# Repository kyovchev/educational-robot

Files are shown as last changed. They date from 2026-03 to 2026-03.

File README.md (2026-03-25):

# MECHO: Modular Extensible Cobot for Human-Centered Operations

This repository contains files for the development of modular robotic arm platform.

The platform is based on the well-known Feetech STS3215-12V smart servo motors: [https://www.dfrobot.com/product-2962.html](https://www.dfrobot.com/product-2962.html).

It was also tested with Herkulex DRS-0101, but they have requirement for 7.5V power supply and encoder with a lower resolution. Also, the Dynamixel AX-12A was considered, but the dimensions were not suitable for the application.

Different constructions can be built by using the following parts:

1. Actuator motor housing;
2. Actuator output ring;
3. 90-degree bracket cover;
4. 15 mm spacer;
5. 90-degree bracket;
6. Base clamp mount bracket;
7. Base box;
8. Base cover;
9. Gripper mounting bracket;
10. Tool mounting bracket.

The parts are shown in the following image:

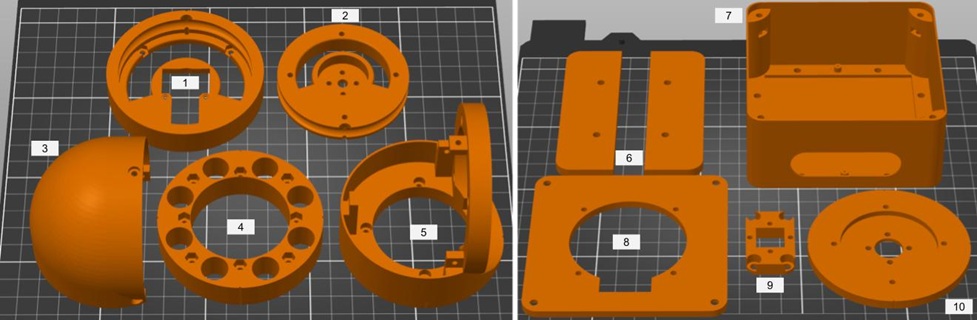
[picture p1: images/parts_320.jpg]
Parts


For the robotic gripper the Micro Servo Parallel Gripper by Techniccontroller is used: [https://grabcad.com/library/micro-servo-parallel-gripper-1](https://grabcad.com/library/micro-servo-parallel-gripper-1).

Currently, the control box of the robot. For the control of the robot an [Arduino Mega 2560 board](https://store.arduino.cc/products/arduino-mega-2560-rev3) is used. for the communication with the servo motors a dedicated [Serial Bus Servo Driver Board](https://www.dfrobot.com/product-3002.html) is connected to a UART port of the Arduino. An additional [25W DC-DC Power Module](https://www.dfrobot.com/product-752.html) is added to the control box for providing stable 5V output for the end effector and if needed also for the Arduino.

The robot assembled in a 6 degree of freedom configuration and the control box are shown in the following image.

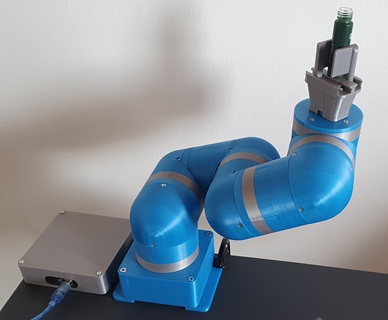
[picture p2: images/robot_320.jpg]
Robot and control box


## Experiments and Videos

Executions of the Task Board v2023 tasks: button press and circuit probing tasks of the Task Board v2023: [https://github.com/peterso/robotlearningblock](https://github.com/peterso/robotlearningblock) are shown in the following video: [https://youtu.be/xAtnlniCpGE](https://youtu.be/Kb3CY3zpSdE).

Demonstration of the execution of a task to pick up a bottle lying in a horizontal position and place it in another place, but this time in a vertical position is shown in the following video: [https://youtu.be/xAtnlniCpGE](https://youtu.be/xAtnlniCpGE).

The Pack Bottle Task Executed by the Education Cobot (https://youtu.be/xAtnlniCpGE)

## CAD and STL files

In the folder [CAD](./CAD/) you can find the source CAD files. They were delevoped by using the FreeCAD software: [https://www.freecad.org/](https://www.freecad.org/).

Differenr robot configurations with 4, 5 or 6 degrees of freedom in a CAD environment can be found in the folder [CAD/Assemblies](./CAD/Assemblies/).

In the folder [STLs](./STLs/) you can find the exported STL files which can be 3D printed.

## Kinematics

In the folder [Kinematics](./Kinematics/) you will find a useful example Jupyter notebooks which shows how the forward and inverse kinematics can be solved by using Robotics Toolbox for Python.

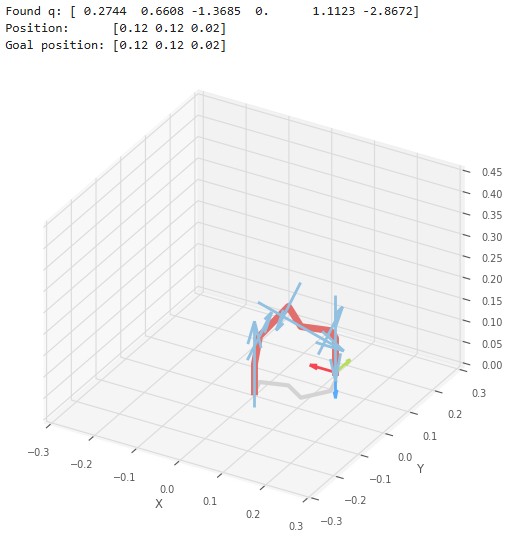
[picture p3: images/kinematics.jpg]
Inverse kinematics


## Software

The folder [Software](./Software/) contains useful Python packages and application for the control of the robot when STS3215 servo motors are used. 

You can run the control software with the following commands:

```bash
cd Software
python app.py
```

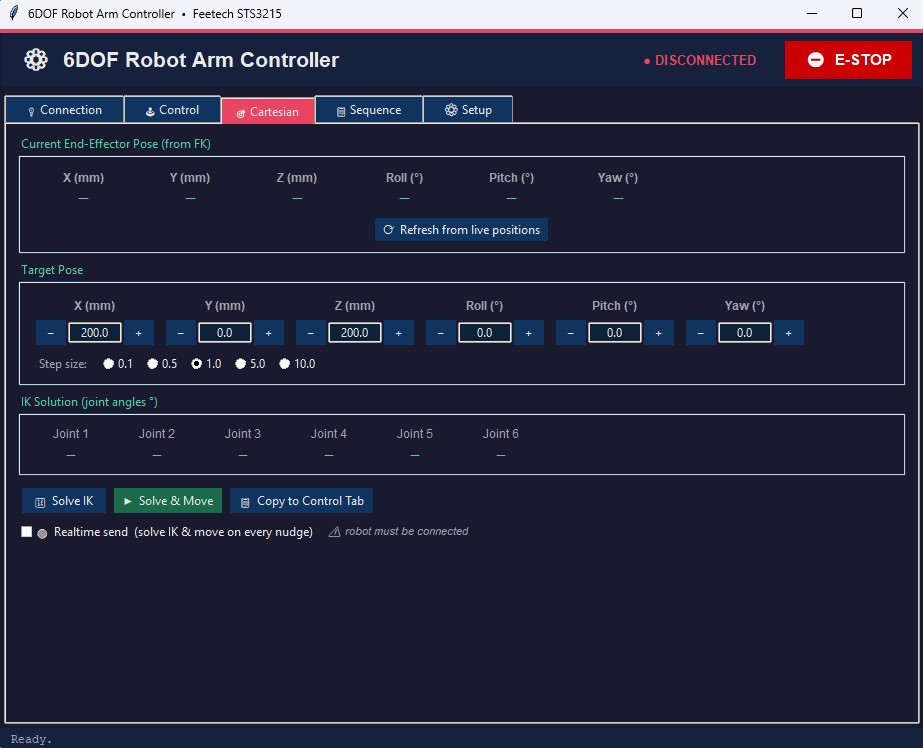
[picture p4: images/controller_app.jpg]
Robot Arm Controller App


It is still under active development.

There are also `robot_api` and `robot_arm` python packages which can be installed locally and used for coding python programs for the control of the robot. The packages can be installed locally in editable mode with: `pip install -e .`. An example program can be found in [./Software/test_api.py](./Software/test_api.py). This API is similar to the Python API for the commercial xArm cobots: [https://github.com/xArm-Developer/xArm-Python-SDK](https://github.com/xArm-Developer/xArm-Python-SDK).

You can also find the firmware for the Arduino board in the folder [./Software/arduino_controller/](./Software/arduino_controller/). This firware allows you to use a regular PWM (micro) servo for the gripper. The firmware will assign to it a virtual ID 7 and be able to control it with the same library and commands as those for the other smart STS3215-12V servos. The library for the servos is described in [https://github.com/vassar-robotics/feetech-servo-sdk](https://github.com/vassar-robotics/feetech-servo-sdk).

## License

Everything is this repository is licensed under the standard MIT license.

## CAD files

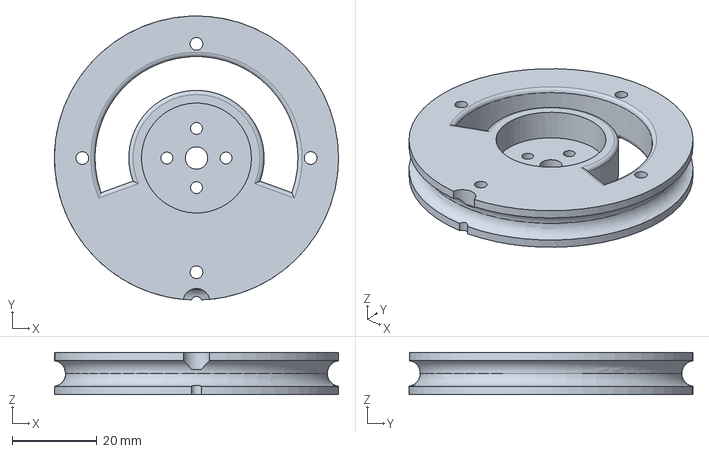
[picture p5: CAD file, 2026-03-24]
CAD/STSActuator.FCStd
67.2 x 67.2 x 10.0 mm

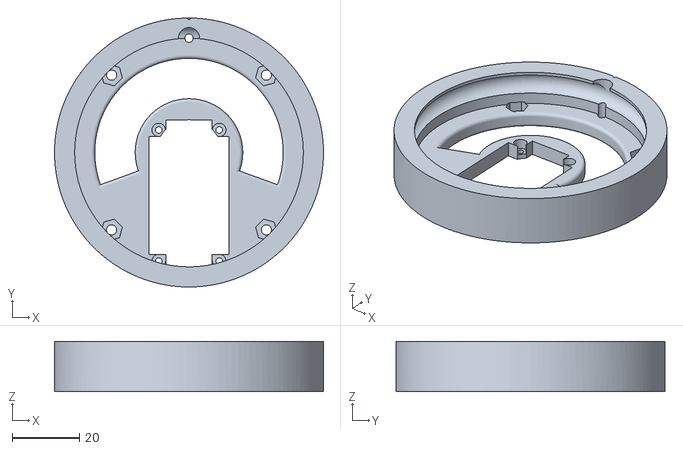
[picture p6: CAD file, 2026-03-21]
STLs/HerkulexActuator-MotorRing.stl
80.0 x 80.0 x 15.0

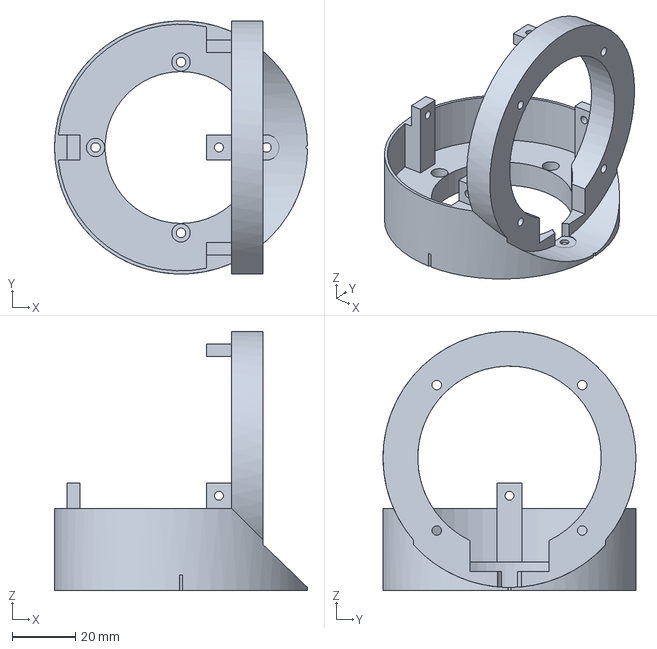
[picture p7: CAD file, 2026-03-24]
CAD/Body.FCStd
80.0 x 80.0 x 82.0 mm

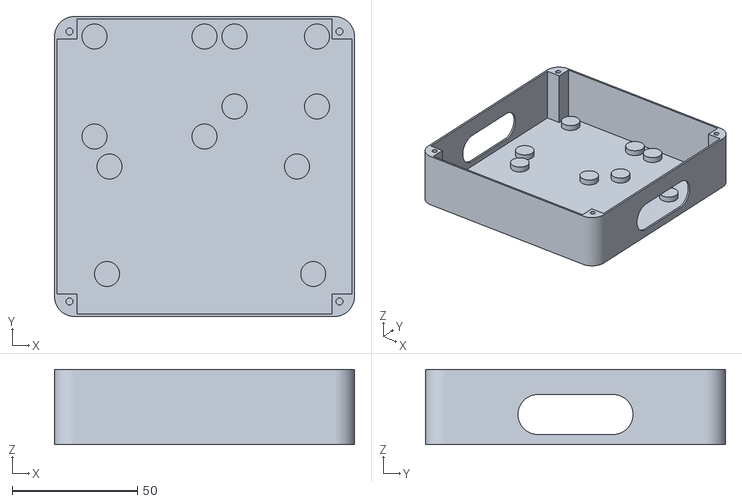
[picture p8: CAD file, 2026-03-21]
STLs/ControlBox-Box.stl
120.0 x 120.0 x 30.0

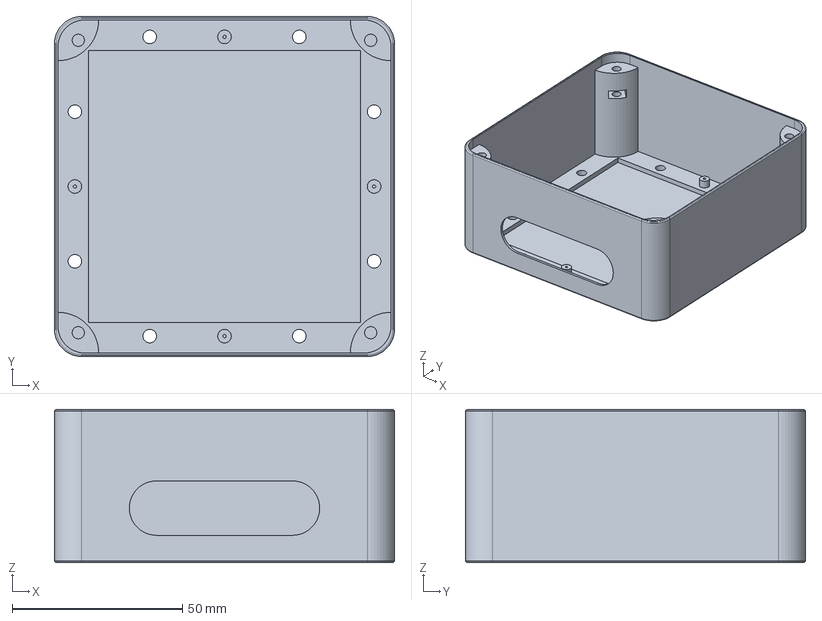
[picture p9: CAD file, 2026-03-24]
CAD/Base.FCStd
100.0 x 100.0 x 45.0 mm

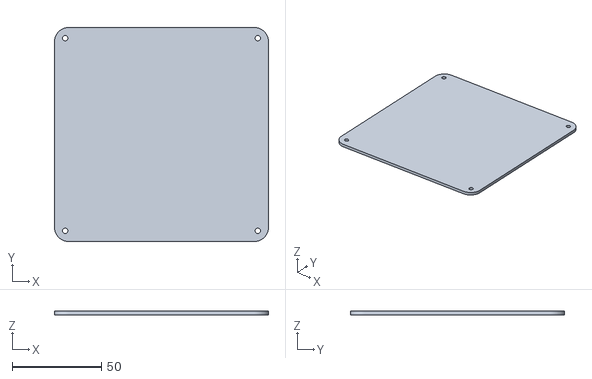
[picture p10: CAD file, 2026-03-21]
STLs/ControlBox-Cover.stl
120.0 x 120.0 x 2.00

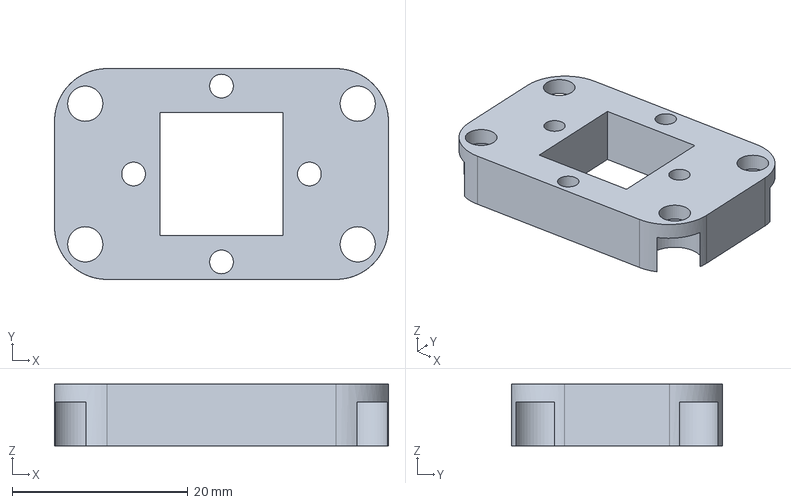
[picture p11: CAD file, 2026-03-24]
CAD/ToolMount.FCStd
38.0 x 24.0 x 7.00 mm

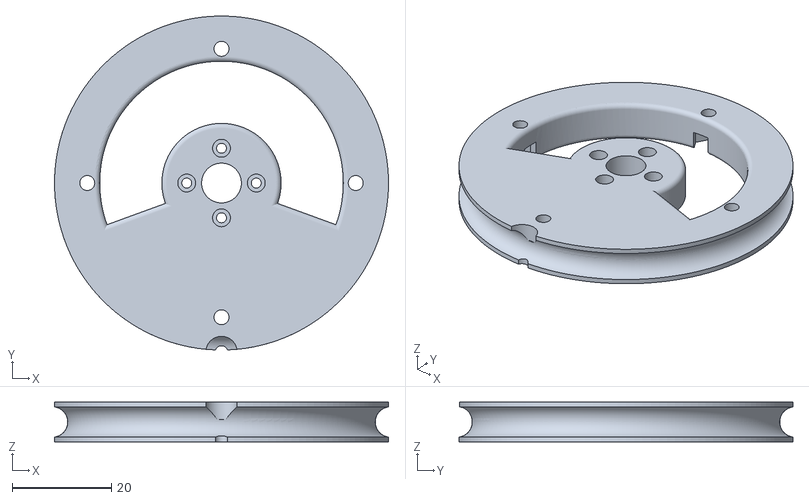
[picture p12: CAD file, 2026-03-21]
STLs/HerkulexActuator-OutputRing.stl
67.2 x 67.2 x 8.00

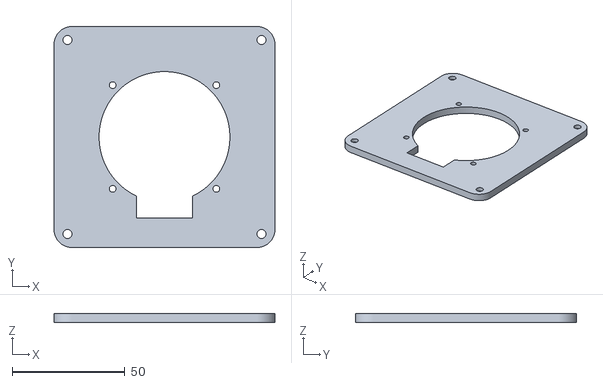
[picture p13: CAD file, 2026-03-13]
STLs/Base-Cover.stl
98.0 x 98.0 x 4.00

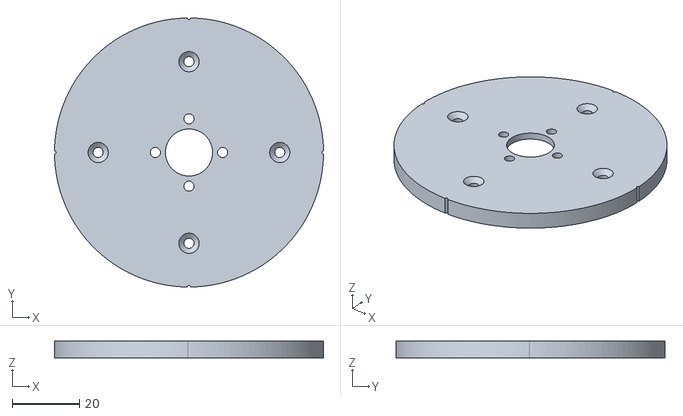
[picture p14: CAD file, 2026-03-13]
STLs/ToolMount-MountHole.stl
80.0 x 80.0 x 5.00

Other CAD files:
CAD/Assemblies/ControlBoxAssembly.FCStd
CAD/Assemblies/Robot-5-DOF-V2.FCStd
CAD/Assemblies/Robot-6-DOF-V3.FCStd
CAD/HerkulexActuator.FCStd
CAD/Assemblies/Robot-4-DOF.FCStd
CAD/ControlBox.FCStd
STLs/STSActuator-OutputRing.stl
CAD/Assemblies/Robot-6-DOF.FCStd
CAD/Assemblies/Robot-5-DOF-V1.FCStd
CAD/Assemblies/Robot-6-DOF-V1.FCStd
CAD/Assemblies/Robot-6-DOF-V2.FCStd
STLs/Base-Box.stl
STLs/Base-Bracket.stl
STLs/Body-90degree.stl
STLs/Body-90degreeCover.stl
STLs/Body-Spacer.stl
STLs/STSActuator-MotorRing.stl
STLs/ToolMount-GripperBracketHole.stl

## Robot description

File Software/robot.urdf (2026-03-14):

<?xml version="1.0" encoding="utf-8"?>
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
<robot name="robot">

  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
  <link name="base_link">
    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
  </link>

  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
  <link name="link0">
    <inertial>
      <mass value="0.10"/>
      <origin xyz="0 0 0.0325" rpy="0 0 0"/>
      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
    </inertial>
    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
  </link>

  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
  <link name="link1">
    <inertial>
      <mass value="0.10"/>
      <origin xyz="0 0.0205 0.0210" rpy="0 0 0"/>
      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
    </inertial>
    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
  </link>

  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
  <link name="link2">
    <inertial>
      <mass value="0.10"/>
      <origin xyz="0 -0.0490 0.0005" rpy="0 0 0"/>
      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
    </inertial>
    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
  </link>

  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
  <link name="link3">
    <inertial>
      <mass value="0.10"/>
      <origin xyz="0 0.0205 0.0210" rpy="0 0 0"/>
      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
    </inertial>
    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
  </link>

  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
  <link name="link4">
    <inertial>
      <mass value="0.10"/>
      <origin xyz="0 0.0205 0.0285" rpy="0 0 0"/>
      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
    </inertial>
    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
  </link>

  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
  <link name="link5">
    <inertial>
      <mass value="0.10"/>
      <origin xyz="0 -0.0205 0.0210" rpy="0 0 0"/>
      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
    </inertial>
    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
  </link>

  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
  <link name="link6">
    <inertial>
      <mass value="0.05"/>
      <origin xyz="0 0 0.040" rpy="0 0 0"/>
      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
    </inertial>
    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
  </link>

  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
  <link name="tool0">
    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
  </link>

  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
  <joint name="base_to_link0" type="fixed">
    <parent link="base_link"/>
    <child link="link0"/>
    <origin xyz="0 0 0" rpy="0 0 0"/>
  </joint>

  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
  <joint name="joint0" type="revolute">
    <parent link="link0"/>
    <child link="link1"/>
    <origin xyz="0 0 0.065" rpy="0 0 0"/>
    <axis xyz="0 0 1"/>
    <limit lower="-2.268928" upper="2.268928" effort="10.0" velocity="3.14159265"/>
    <dynamics damping="0.01" friction="0.0"/>
  </joint>

  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
  <joint name="joint1" type="revolute">
    <parent link="link1"/>
    <child link="link2"/>
    <origin xyz="0 0.041 0.042" rpy="-1.57079632 0 0"/>
    <axis xyz="0 0 1"/>
    <limit lower="-2.268928" upper="2.268928" effort="10.0" velocity="3.14159265"/>
    <dynamics damping="0.01" friction="0.0"/>
  </joint>

  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
  <joint name="joint2" type="revolute">
    <parent link="link2"/>
    <child link="link3"/>
    <origin xyz="0 -0.098 0.001" rpy="3.14159265 0 0"/>
    <axis xyz="0 0 1"/>
    <limit lower="-2.268928" upper="2.268928" effort="10.0" velocity="3.14159265"/>
    <dynamics damping="0.01" friction="0.0"/>
  </joint>

  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
  <joint name="joint3" type="revolute">
    <parent link="link3"/>
    <child link="link4"/>
    <origin xyz="0 0.041 0.042" rpy="-1.57079632 0 0"/>
    <axis xyz="0 0 1"/>
    <limit lower="-2.268928" upper="2.268928" effort="10.0" velocity="3.14159265"/>
    <dynamics damping="0.01" friction="0.0"/>
  </joint>

  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
  <joint name="joint4" type="revolute">
    <parent link="link4"/>
    <child link="link5"/>
    <origin xyz="0 0.041 0.057" rpy="-1.57079632 0 0"/>
    <axis xyz="0 0 1"/>
    <limit lower="-2.268928" upper="2.268928" effort="10.0" velocity="3.14159265"/>
    <dynamics damping="0.01" friction="0.0"/>
  </joint>

  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
  <joint name="joint5" type="revolute">
    <parent link="link5"/>
    <child link="link6"/>
    <origin xyz="0 -0.041 0.042" rpy="1.57079632 0 0"/>
    <axis xyz="0 0 1"/>
    <limit lower="-3.14" upper="3.14" effort="10.0" velocity="3.14159265"/>
    <dynamics damping="0.01" friction="0.0"/>
  </joint>

  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
  <joint name="joint6_ee" type="fixed">
    <parent link="link6"/>
    <child link="tool0"/>
    <origin xyz="0 0 0.08" rpy="0 0 3.14159265"/>
  </joint>

</robot>

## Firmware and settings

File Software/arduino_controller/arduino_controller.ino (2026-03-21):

#include <Servo.h>

#define VIRTUAL_ID 7
#define PWM_PIN 6
#define PWM_MIN_US 500
#define PWM_MAX_US 2500
#define STS_POS_MAX 4095

#define REG_GOAL_ACC 0x29
#define REG_GOAL_POS 0x2A
#define REG_PRESENT_POS 0x38
#define REG_MOVING 0x3A
#define REG_VOLTAGE 0x3E
#define REG_TEMP 0x3F
#define REG_TORQUE_EN 0x28
#define REG_ID 0x05
#define REG_BAUD 0x06

#define INST_PING 0x01
#define INST_READ 0x02
#define INST_WRITE 0x03
#define INST_REG_WRITE 0x04
#define INST_ACTION 0x05
#define INST_SYNC_WRITE 0x83
#define BROADCAST_ID 0xFE

// ── Parser ────────────────────────────────────────────────────────────────────
#define PKT_MAX 128
uint8_t pkt[PKT_MAX];
uint16_t pktTotal = 0;
uint16_t pktIdx = 0;
uint8_t parserState = 0;  // 0=idle 1=hdr2 2=len 3=data

// ── Virtual servo state ───────────────────────────────────────────────────────
Servo pwm;
int16_t vPos = 2047;
uint8_t vTorque = 1;
uint8_t vMoving = 0;
uint8_t vVolt = 74;
uint8_t vTemp = 25;
bool pending = false;
int16_t pendingPos = 2047;

// ── Helpers ───────────────────────────────────────────────────────────────────
static inline int16_t le16(uint8_t lo, uint8_t hi) {
  return (int16_t)(((uint16_t)hi << 8) | lo);
}

void setPos(int16_t pos) {
  if (pos < 0) pos = 0;
  if (pos > STS_POS_MAX) pos = STS_POS_MAX;
  vPos = pos;
  pwm.writeMicroseconds(
    (int)map((long)pos, 0L, (long)STS_POS_MAX, (long)PWM_MIN_US, (long)PWM_MAX_US));
}

void respond(uint8_t error, const uint8_t *data, uint8_t n) {
  uint8_t len = n + 2;
  uint16_t s = (uint16_t)VIRTUAL_ID + len + error;
  Serial.write((uint8_t)0xFF);
  Serial.write((uint8_t)0xFF);
  Serial.write((uint8_t)VIRTUAL_ID);
  Serial.write(len);
  Serial.write(error);
  for (uint8_t i = 0; i < n; i++) {
    Serial.write(data[i]);
    s += data[i];
  }
  Serial.write((uint8_t)((~s) & 0xFF));
}

void ack() {
  const uint8_t e[1] = { 0 };
  respond(0, e, 0);
}

void handleRead(uint8_t startReg, uint8_t count) {
  uint8_t resp[32];
  uint8_t ri = 0;
  for (uint8_t r = startReg; r < (uint8_t)(startReg + count) && ri < 32; r++) {
    switch (r) {
      case REG_ID: resp[ri++] = VIRTUAL_ID; break;
      case REG_BAUD: resp[ri++] = 0; break;
      case REG_TORQUE_EN: resp[ri++] = vTorque; break;
      case REG_GOAL_POS: resp[ri++] = (uint8_t)(vPos & 0xFF); break;
      case REG_GOAL_POS + 1: resp[ri++] = (uint8_t)((vPos >> 8) & 0xFF); break;
      case REG_PRESENT_POS: resp[ri++] = (uint8_t)(vPos & 0xFF); break;
      case REG_PRESENT_POS + 1: resp[ri++] = (uint8_t)((vPos >> 8) & 0xFF); break;
      case REG_MOVING: resp[ri++] = vMoving; break;
      case REG_VOLTAGE: resp[ri++] = vVolt; break;
      case REG_TEMP: resp[ri++] = vTemp; break;
      default: resp[ri++] = 0; break;
    }
  }
  respond(0, resp, ri);
}

void handleVirtual() {
  uint8_t instr = pkt[4];
  uint8_t *P = pkt + 5;
  uint8_t nP = (pkt[3] >= 2) ? pkt[3] - 2 : 0;
  switch (instr) {
    case INST_PING: ack(); break;
    case INST_READ: (nP >= 2) ? handleRead(P[0], P[1]) : ack(); break;
    case INST_WRITE:
      if (nP >= 1) {
        if (P[0] == REG_GOAL_ACC && nP >= 4) setPos(le16(P[2], P[3]));
        else if (P[0] == REG_GOAL_POS && nP >= 3) setPos(le16(P[1], P[2]));
        else if (P[0] == REG_TORQUE_EN && nP >= 2) vTorque = P[1];
      }
      ack();
      break;
    case INST_REG_WRITE:
      if (nP >= 4 && P[0] == REG_GOAL_ACC) {
        pendingPos = le16(P[2], P[3]);
        pending = true;
      } else if (nP >= 3 && P[0] == REG_GOAL_POS) {
        pendingPos = le16(P[1], P[2]);
        pending = true;
      }
      ack();
      break;
    case INST_ACTION:
      if (pending) {
        setPos(pendingPos);
        pending = false;
      }
      ack();
      break;
    default: ack(); break;
  }
}

void handleSync() {
  uint8_t *P = pkt + 5;
  uint8_t nP = (pkt[3] >= 2) ? pkt[3] - 2 : 0;
  if (nP < 4) goto forward;
  {
    uint8_t startReg = P[0];
    uint8_t dataPerServo = P[1];
    uint8_t off = 2;
    while (off + 1 + dataPerServo <= nP) {
      if (P[off] == VIRTUAL_ID) {
        uint8_t *D = P + off + 1;
        if (startReg == REG_GOAL_ACC && dataPerServo >= 3) setPos(le16(D[1], D[2]));
        else if (startReg == REG_GOAL_POS && dataPerServo >= 2) setPos(le16(D[0], D[1]));
      }
      off += 1 + dataPerServo;
    }
  }
forward:
  // Forward full packet to real bus (real servos ignore ID 99)
  Serial3.write(pkt, 4 + pkt[3]);
}

// ── setup / loop ──────────────────────────────────────────────────────────────
void setup() {
  pwm.attach(PWM_PIN, PWM_MIN_US, PWM_MAX_US);
  pwm.writeMicroseconds(1500);
  Serial.begin(1000000);
  Serial3.begin(1000000);
}

void loop() {
  while (Serial.available()) {
    uint8_t b = Serial.read();

    switch (parserState) {
      case 0:  // idle — wait for first 0xFF
        if (b == 0xFF) {
          pkt[0] = b;
          pktIdx = 1;
          parserState = 1;
        }
        break;

      case 1:  // wait for second 0xFF (absorb extra 0xFF)
        if (b == 0xFF) {
          pkt[1] = b;
          pktIdx = 2;
        } else {
          pkt[1] = 0xFF;
          pkt[2] = b;
          pktIdx = 3;
          parserState = 2;
        }
        break;

      case 2:  // LEN
        pkt[3] = b;
        pktIdx = 4;
        if (b < 2 || (4 + (uint16_t)b) > PKT_MAX) {
          parserState = 0;
          break;
        }
        pktTotal = 4 + b;
        parserState = 3;
        break;

      case 3:  // DATA
        pkt[pktIdx++] = b;
        if (pktIdx < pktTotal) break;
        {
          // verify checksum
          uint16_t s = 0;
          for (uint16_t i = 2; i < pktTotal - 1; i++) s += pkt[i];
          if (((~s) & 0xFF) == pkt[pktTotal - 1]) {
            uint8_t id = pkt[2];
            uint8_t instr = pkt[4];
            if (instr == INST_SYNC_WRITE) handleSync();
            else if (id == VIRTUAL_ID) handleVirtual();
            else {
              // forward to real bus, proxy response back
              Serial3.write(pkt, pktTotal);
              // forward response back to PC
              uint32_t t = millis();
              uint8_t h = 0;
              uint8_t rb[64];
              uint8_t ri = 0;
              uint8_t rlen = 0;
              uint8_t phase = 0;
              while (millis() - t < 10) {
                if (!Serial3.available()) continue;
                uint8_t c = Serial3.read();
                t = millis();
                if (phase == 0) {
                  if (c == 0xFF) phase = 1;
                } else if (phase == 1) {
                  if (c == 0xFF) phase = 2;
                  else phase = 0;
                } else if (phase == 2) {
                  rb[ri++] = c;
                  phase = 3;
                } else if (phase == 3) {
                  rb[ri++] = c;
                  rlen = c;
                  phase = 4;
                } else if (phase == 4) {
                  rb[ri++] = c;
                  if (ri >= rlen + 2) {
                    Serial.write((uint8_t)0xFF);
                    Serial.write((uint8_t)0xFF);
                    Serial.write(rb, ri);
                    break;
                  }
                }
              }
            }
          }
        }
        parserState = 0;
        break;
    }
  }
}

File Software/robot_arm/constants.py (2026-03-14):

# ─────────────────────────────────────────────
#  STS3215 Protocol Constants
# ─────────────────────────────────────────────
STS_HEADER = 0xFF
STS_BROADCAST_ID = 0xFE

INST_PING = 0x01
INST_READ = 0x02
INST_WRITE = 0x03
INST_SYNC_WRITE = 0x83

REG_ID = 0x05
REG_EEPROM_MIN_ANGLE = 0x09   # EEPROM min angle limit (2 bytes)
REG_EEPROM_MAX_ANGLE = 0x0B   # EEPROM max angle limit (2 bytes)
# EEPROM max speed limit (2 bytes) — persists across reboots
REG_EEPROM_MAX_SPEED = 0x0F
# decimal 40 — also used for one-key calibration (write 128)
REG_TORQUE_ENABLE = 0x28
REG_LOCK = 0x37   # decimal 55 — RAM lock: 0=EEPROM writes allowed, 1=locked
# decimal 41 — acceleration (1 byte); WritePos starts here
REG_GOAL_ACC = 0x29
# decimal 42 — goal position (2 bytes, little-endian)
REG_GOAL_POSITION = 0x2A
REG_GOAL_SPEED = 0x2E   # decimal 46 — goal speed   (2 bytes, little-endian)
REG_PRESENT_POSITION = 0x38   # decimal 56
REG_MOVING = 0x3A   # decimal 58 — 1=moving, 0=reached target
REG_PRESENT_TEMP = 0x3F   # decimal 63
REG_PRESENT_VOLTAGE = 0x3E   # decimal 62

# One-key calibration: write 128 to REG_TORQUE_ENABLE (after EEPROM unlock)
CALIBRATE_CMD = 128

POS_MIN = 0
POS_MAX = 4095
DEG_MAX = 360.0
POS_CENTER = 2047   # maps to 0° logical
MIN_ANGLE = -130
MAX_ANGLE = 130
SPEED = 1500
ACC = 200

NUM_ARM_JOINTS = 6   # revolute joints used in FK/IK
JOINT_NAMES = [f"Joint {i+1}" for i in range(6)] + ["Gripper"]
NUM_JOINTS = len(JOINT_NAMES)  # 7 total

# ─────────────────────────────────────────────
#  Theme palettes
# ─────────────────────────────────────────────
THEMES = {
    "dark": {
        "BG":         "#1a1a2e",
        "PANEL":      "#16213e",
        "ACCENT":     "#0f3460",
        "ORANGE":     "#e94560",
        "GREEN":      "#4ecca3",
        "TEXT":       "#eaeaea",
        "SUBTEXT":    "#a0a0b0",
        "ENTRY":      "#0d2137",
        "DANGER_BTN": "#8b0000",
        "GREEN_BTN":  "#1a6b4a",
        "SEL_BG":     "#0f3460",
    },
    "light": {
        "BG":         "#f0f2f5",
        "PANEL":      "#dde1ea",
        "ACCENT":     "#4a90d9",
        "ORANGE":     "#d0392b",
        "GREEN":      "#217a52",
        "TEXT":       "#1a1a2a",
        "SUBTEXT":    "#555577",
        "ENTRY":      "#ffffff",
        "DANGER_BTN": "#c0392b",
        "GREEN_BTN":  "#217a52",
        "SEL_BG":     "#4a90d9",
    },
}

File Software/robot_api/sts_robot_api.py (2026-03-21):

"""
STS Robot API  —  XArmAPI-compatible interface for a 6-DOF robot
                  built with Feetech STS3215 servos.

Drop-in replacement for XArmAPI / XArmEmulator.
Kinematics are handled by roboticstoolbox + a URDF file.

Usage (TCP / Wi-Fi ESP32 bridge)
---------------------------------
    from sts_robot_api import StsRobotAPI as XArmAPI

    robot = StsRobotAPI("192.168.1.100")          # TCP, default port 8888
    robot.motion_enable(enable=True)
    robot.set_mode(0)
    robot.set_state(state=0)
    code, pos = robot.get_position()              # [x, y, z, roll, pitch, yaw]
    robot.set_position(x=250, y=0, z=300, roll=180, pitch=0, yaw=0, wait=True)

Usage (USB serial)
------------------
    robot = StsRobotAPI(port="COM3")              # or "/dev/ttyUSB0"
    robot.motion_enable(enable=True)
    ...

Usage (offline emulator)
------------------------
    from sts_robot_api import StsRobotEmulator as XArmAPI
    robot = StsRobotEmulator()
    ...

Config file (JSON)
------------------
    robot = StsRobotAPI("192.168.1.100", config="robot_config.json")

Return codes
------------
    CODE_SUCCESS =  0
    CODE_WARN    =  1
    CODE_ERROR   = -1

All methods that return a status code follow the XArmAPI convention:
    (code, value)  for getters
    code           for setters / commands
"""

from __future__ import annotations

import json
import math
import threading
import time
from dataclasses import asdict
from typing import Callable, List, Optional, Tuple

# ── internal modules ─────────────────────────────────────────────────────────
from robot_arm.constants import (POS_CENTER, POS_MIN, POS_MAX,
                                 NUM_JOINTS, NUM_ARM_JOINTS)
from robot_arm.driver import STS3215Driver
from robot_arm.kinematics import Kinematics
from robot_arm.models import JointConfig, RobotConfig, Waypoint

# ── return codes (mirrors XArmAPI) ───────────────────────────────────────────
CODE_SUCCESS = 0
CODE_WARN = 1
CODE_ERROR = -1

# ── robot states ─────────────────────────────────────────────────────────────
STATE_READY = 0
STATE_MOVING = 1
STATE_PAUSED = 3
STATE_ERROR = 4

# ── default gripper open/close range (degrees) ───────────────────────────────
GRIPPER_OPEN = 0.0
GRIPPER_CLOSED = 90.0


# ─────────────────────────────────────────────────────────────────────────────
#  StsRobotAPI
# ─────────────────────────────────────────────────────────────────────────────
class StsRobotAPI:
    """
    XArmAPI-compatible controller for a 6-DOF STS3215 servo robot.

    Parameters
    ----------
    ip : str | None
        ESP32 IP address for TCP/Wi-Fi connection.
        Pass None (or omit) when using a serial port.
    port : str | None
        Serial port string, e.g. "COM3" or "/dev/ttyUSB0".
        Ignored when `ip` is provided.
    tcp_port : int
        TCP port on the ESP32 bridge (default 8888).
    baud : int
        Serial baud rate (default 1 000 000).
    urdf_path : str
        Path to the URDF file for FK/IK.
    config : str | None
        Path to a JSON config file (joint IDs, limits, offsets …).
    is_radian : bool
        If True, angle arguments/returns use radians instead of degrees.
        Mirrors XArmAPI convention (default False).
    """

    CODE_SUCCESS = CODE_SUCCESS
    CODE_WARN = CODE_WARN
    CODE_ERROR = CODE_ERROR

    STATE_READY = STATE_READY
    STATE_MOVING = STATE_MOVING
    STATE_PAUSED = STATE_PAUSED
    STATE_ERROR = STATE_ERROR

    def __init__(self,
                 ip:        Optional[str] = None,
                 port:      Optional[str] = None,
                 tcp_port:  int = 8888,
                 baud:      int = 1_000_000,
                 urdf_path: str = "robot.urdf",
                 config:    Optional[str] = None,
                 is_radian: bool = False):

        self.ip = ip
        self._serial_port = port
        self._tcp_port = tcp_port
        self._baud = baud
        self.is_radian = is_radian

        self._driver = STS3215Driver()
        self._kinematics = Kinematics(urdf_path)
        self._cfg = RobotConfig()

        if config:
            self._load_config(config)

        # live state
        self._live_positions: List[Optional[float]] = [None] * NUM_JOINTS
        self._live_raw:       List[Optional[int]] = [None] * NUM_JOINTS
        self._target_angles:  List[float] = [0.0] * NUM_JOINTS

        self._state = STATE_READY
        self._error_code = 0
        self._motion_enabled = False
        self._mode = 0
        self._connected = False

        self._poll_running = False
        self._poll_thread:  Optional[threading.Thread] = None
        self._move_lock = threading.Lock()

        # user callbacks
        self.on_position_update: Optional[Callable[[int, float], None]] = None

        # auto-connect
        self._auto_connect()

    # ── auto connect ─────────────────────────────────────────────────────────
    def _auto_connect(self):
        if self.ip:
            ok = self._driver.connect_tcp(self.ip, self._tcp_port)
        elif self._serial_port:
            ok = self._driver.connect_serial(self._serial_port, self._baud)
        else:
            print("[StsRobotAPI] No ip or port given — not connected.")
            return
        if ok:
            self._connected = True
            self._start_polling()
            print(f"[StsRobotAPI] Connected to "
                  f"{'TCP ' + self.ip + ':' + str(self._tcp_port) if self.ip else self._serial_port}")
        else:
            print("[StsRobotAPI] Connection failed.")

    # ── XArmAPI: connect / disconnect ────────────────────────────────────────
    def connect(self) -> int:
        if self._connected:
            return CODE_SUCCESS
        self._auto_connect()
        return CODE_SUCCESS if self._connected else CODE_ERROR

    def disconnect(self) -> int:
        self._stop_polling()
        self._driver.disconnect()
        self._connected = False
        print("[StsRobotAPI] Disconnected.")
        return CODE_SUCCESS

    # ── XArmAPI: enable / mode / state ───────────────────────────────────────
    def motion_enable(self, enable: bool = True,
                      servo_id: Optional[int] = None) -> int:
        self._motion_enabled = enable
        if self._connected:
            for i, jcfg in enumerate(self._cfg.joints):
                if servo_id is None or jcfg.servo_id == servo_id:
                    self._driver.set_torque(jcfg.servo_id, enable)
        status = "enabled" if enable else "disabled"
        print(f"[StsRobotAPI] Motion {status}.")
        return CODE_SUCCESS

    def set_mode(self, mode: int) -> int:
        """
        0 = position mode  (normal operation)
        1 = servo/joint mode
        2 = teach / zero-torque mode
        """
        self._mode = mode
        if mode == 2:
            self.motion_enable(False)
        names = {0: "Position", 1: "Servo", 2: "Teach"}
        print(f"[StsRobotAPI] Mode: {names.get(mode, str(mode))}")
        return CODE_SUCCESS
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

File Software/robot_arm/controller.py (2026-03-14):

"""High-level robot controller: kinematics, sequencing, persistence."""

import json
import threading
import time
from dataclasses import asdict
from typing import Callable, Optional

from .constants import POS_CENTER, POS_MIN, POS_MAX, NUM_JOINTS
from .driver import STS3215Driver
from .kinematics import Kinematics
from .models import JointConfig, RobotConfig, Waypoint


class RobotController:
    def __init__(self, urdf_path: str = "robot.urdf"):
        self.driver   = STS3215Driver()
        self.config   = RobotConfig()
        self.sequence: list[Waypoint] = []
        self.kinematics = Kinematics(urdf_path)

        self.live_positions: list[Optional[float]] = [None] * NUM_JOINTS
        self.live_raw:       list[Optional[int]]   = [None] * NUM_JOINTS

        self._poll_running = False
        self._seq_running  = False
        self._poll_thread: Optional[threading.Thread] = None
        self._seq_thread:  Optional[threading.Thread] = None

        # callbacks
        self.on_position_update: Optional[Callable[[int, float], None]] = None

    # ── connection ──────────────────────────────────────────────────────────
    def connect(self, port: str, baud: int = 1_000_000) -> bool:
        self.config.port = port
        self.config.baud = baud
        ok = self.driver.connect_serial(port, baud)
        if ok:
            self._start_polling()
        return ok

    def connect_tcp(self, host: str, port: int = 8888) -> bool:
        self.config.tcp_host = host
        self.config.tcp_port = port
        ok = self.driver.connect_tcp(host, port)
        if ok:
            self._start_polling()
        return ok

    def disconnect(self):
        self._stop_polling()
        self.driver.disconnect()

    # ── polling ─────────────────────────────────────────────────────────────
    def _start_polling(self):
        self._poll_running = True
        self._poll_thread  = threading.Thread(target=self._poll_loop, daemon=True)
        self._poll_thread.start()

    def _stop_polling(self):
        self._poll_running = False
        if self._poll_thread:
            self._poll_thread.join(timeout=2)

    def _poll_loop(self):
        while self._poll_running:
            for i, jcfg in enumerate(self.config.joints):
                raw = self.driver.get_present_position(jcfg.servo_id)
                if raw is not None:
                    self.live_raw[i] = raw
                    deg = self._raw_to_logical(i, raw)
                    self.live_positions[i] = deg
                    if self.on_position_update:
                        self.on_position_update(i, deg)
            time.sleep(0.05)

    # ── angle ↔ raw conversion ──────────────────────────────────────────────
    def _raw_to_logical(self, joint_idx: int, raw: int) -> float:
        offset = raw - self.config.joints[joint_idx].zero_offset
        deg    = STS3215Driver.pos_to_deg(offset + POS_CENTER) - 180.0
        return round(-deg, 2)

    def _logical_to_raw(self, joint_idx: int, deg: float) -> int:
        jcfg = self.config.joints[joint_idx]
        deg  = max(jcfg.min_angle, min(jcfg.max_angle, deg))
        pos  = STS3215Driver.deg_to_pos(-deg + 180.0)
        raw  = pos - POS_CENTER + jcfg.zero_offset
        return max(POS_MIN, min(POS_MAX, raw))

    def angles_to_raw(self, angles: list) -> list:
        return [self._logical_to_raw(i, deg) for i, deg in enumerate(angles)]

    # ── joint control ────────────────────────────────────────────────────────
    def set_joint_angle(self, joint_idx: int, deg: float):
        jcfg = self.config.joints[joint_idx]
        raw  = self._logical_to_raw(joint_idx, deg)
        self.driver.set_goal_position(jcfg.servo_id, raw, jcfg.speed, jcfg.acc)

    def set_all_angles(self, angles: list) -> None:
        id_pos_speed = [
            (self.config.joints[i].servo_id,
             self._logical_to_raw(i, deg),
             self.config.joints[i].speed,
             self.config.joints[i].acc)
            for i, deg in enumerate(angles)
        ]
        self.driver.sync_write_positions(id_pos_speed)

    def go_home(self) -> None:
        angles = [jcfg.home_angle for jcfg in self.config.joints]
        self.set_all_angles(angles)

    def torque_all(self, enable: bool):
        for jcfg in self.config.joints:
            self.driver.set_torque(jcfg.servo_id, enable)

    # ── FK helper (uses live positions, substitutes 0 for unread joints) ────
    def compute_fk(self):
        """Return FK pose using current live positions (None → 0.0)."""
        angles = [p if p is not None else 0.0 for p in self.live_positions]
        return self.kinematics.fk(angles)

    # ── IK helper ────────────────────────────────────────────────────────────
    def compute_ik(self, x_mm, y_mm, z_mm, roll_deg, pitch_deg, yaw_deg):
        """
        Compute IK for a Cartesian target.
        Returns list of NUM_ARM_JOINTS angles in degrees, or None.
        """
        pose = self.kinematics.pose_from_components(
            x_mm, y_mm, z_mm, roll_deg, pitch_deg, yaw_deg)
        seed = [p if p is not None else 0.0 for p in self.live_positions]
        return self.kinematics.ik(pose, seed_angles_deg=seed)

    # ── teach mode ───────────────────────────────────────────────────────────
    def enter_teach_mode(self):
        self.torque_all(False)

    def exit_teach_mode(self):
        self.torque_all(True)

    def capture_position(self, name: str) -> Waypoint:
        angles = [p if p is not None else 0.0 for p in self.live_positions]
        wp = Waypoint(name=name, angles=angles)
        self.sequence.append(wp)
        return wp

    # ── sequence playback ────────────────────────────────────────────────────
    def play_sequence(self, loop: bool = False,
                      progress_cb: Optional[Callable] = None,
                      done_cb: Optional[Callable] = None):
        self._seq_running = True

        def _run():
            repeat = True
            while repeat and self._seq_running:
                for idx, wp in enumerate(self.sequence):
                    if not self._seq_running:
                        break
                    if progress_cb:
                        progress_cb(idx, wp)
                    self.set_all_angles(wp.angles)
                    time.sleep(wp.duration)
                repeat = loop and self._seq_running
            self._seq_running = False
            if done_cb:
                done_cb()

        self._seq_thread = threading.Thread(target=_run, daemon=True)
        self._seq_thread.start()

    def stop_sequence(self):
        self._seq_running = False

    # ── setup helpers ────────────────────────────────────────────────────────
    def set_servo_id(self, current_id: int, new_id: int) -> bool:
        return self.driver.set_id(current_id, new_id)
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

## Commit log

2026-03-13 Update CAD
    [Base-Box.stl, Base-Bracket.stl, Base-Cover.stl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]
2026-03-14 Add kinematics notebooks
    [robot.urdf]
2026-03-14 Update joint limits
    [robot.urdf]
2026-03-14 Add complete app and initial python API
    [robot.urdf]
2026-03-21 Add new CAD designs
    [ControlBox.FCStd, ControlBoxAssembly.FCStd, HerkulexActuator.FCStd]
2026-03-21 Add new STLs
    [ControlBox-Box.stl, ControlBox-Cover.stl, HerkulexActuator-MotorRing.stl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]
2026-03-21 Add Arduino firmware for virtual gripper servo
2026-03-24 Udate CAD files
    [Base.FCStd, Body.FCStd, ControlBoxAssembly.FCStd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]
2026-11-02 Update new configuration's URDF
2026-11-04 Add slim actuator design
2026-11-06 Add V2 connector and cover
2026-11-08 Update 50mm robot CAD design
2026-11-11 Add V2 Base CAD design
